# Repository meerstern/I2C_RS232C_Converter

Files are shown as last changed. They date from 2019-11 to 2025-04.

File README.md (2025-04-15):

# I2C_RS232C_Converter
I2C-RS232C Converter with Grove Connector

## 概要 
  * マイコンのI2CポートをRS232C通信ポートに変換するアダプタです
  * マイコンからI2Cデバイスとして制御し、UARTのボーレート設定、送信、受信処理をすることができます
  * I2C/UARTプロトコルブリッジ[SC16IS750][1]とRS232C変換IC ADM3202を搭載しています
  * I2CはGrove互換コネクタとなっており、3.3V/5V電源に対応しています
  * RS232CポートはD-sub9ピンのオスコネクタを搭載しています
  * I2C/UARTプロトコルブリッジSC16IS750は64bytesのバッファを内蔵しています
  * 7.3728MHzの水晶発振子を搭載しており、マイコンのメインクロックから独立してUARTのボーレート設定ができます  
  * デフォルトI2Cアドレスは8bit:0x9A(7bit:0x4D)です  

## 注意 
  * RS232Cレベル変換している信号はD-sub9ピンの受信の2ピン、送信の3ピンのみです  
  * D-sub9ピンの受信の2ピン、送信の3ピン、GNDの5ピン以外はTTLレベルのため、必要に応じて未接続にしてください(v1.0/v1.1のみ)
  * D-sub9ピンの受信の2ピン、送信の3ピン、GNDの5ピン以外のRTS/CDSはRS232Cレベルに変換されています(v1.2以降, v1.3はR14を必要に応じて実装してください)    
  * Arduino Uno以外の場合はサンプルコード内SC16IS750.cppの29行目付近のWire定義を必要に応じて変更してください  

## 販売サイト
  * [スイッチサイエンス][2]

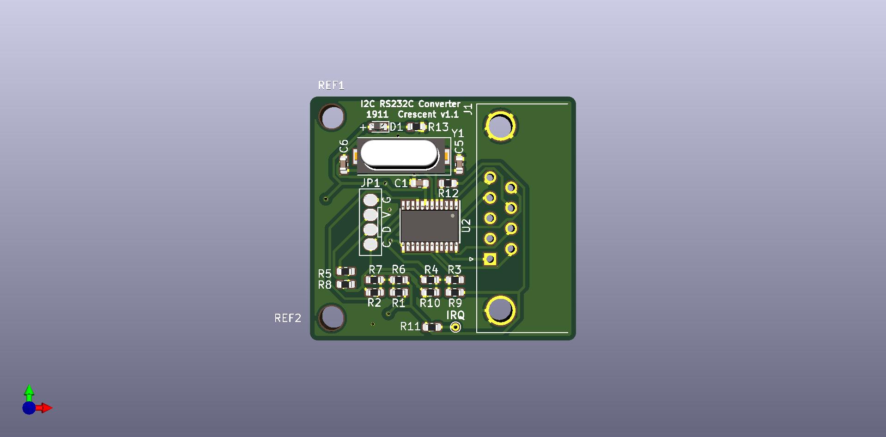
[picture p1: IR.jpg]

   
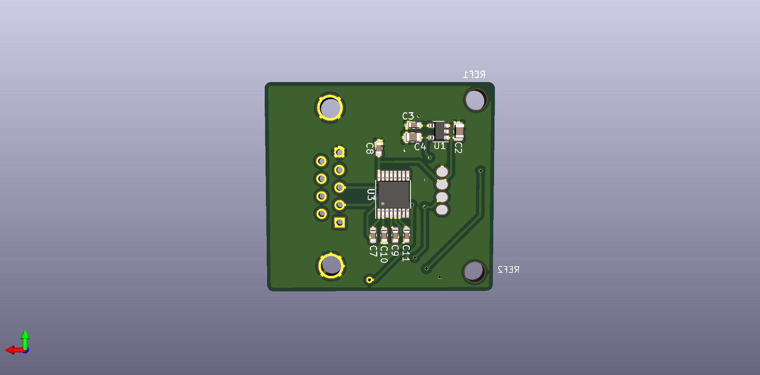
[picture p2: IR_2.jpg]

    
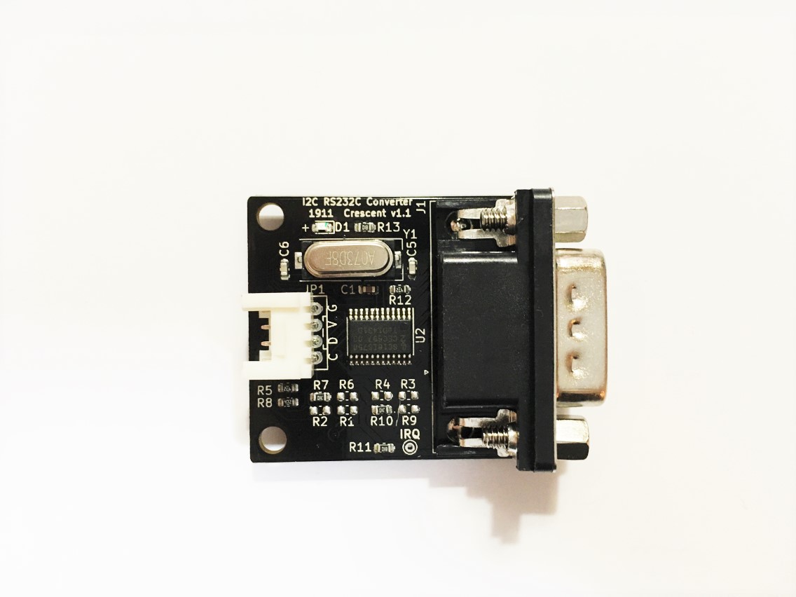
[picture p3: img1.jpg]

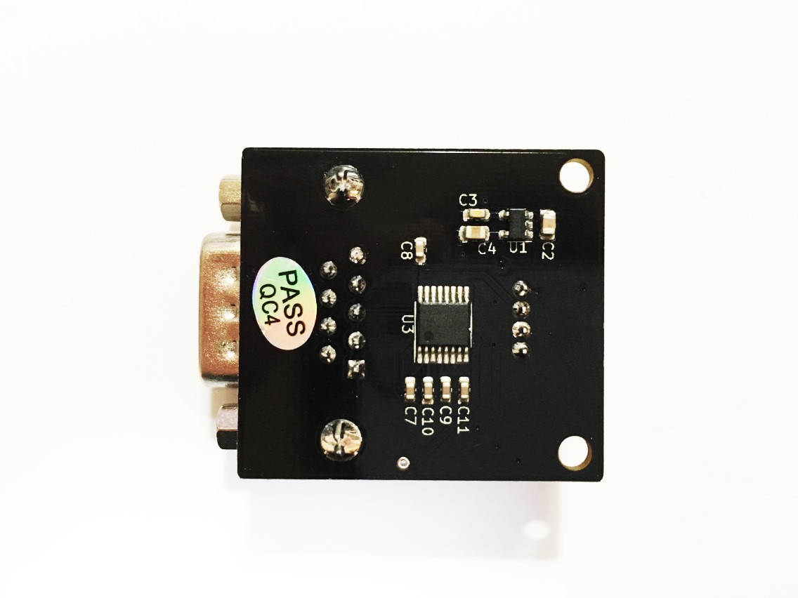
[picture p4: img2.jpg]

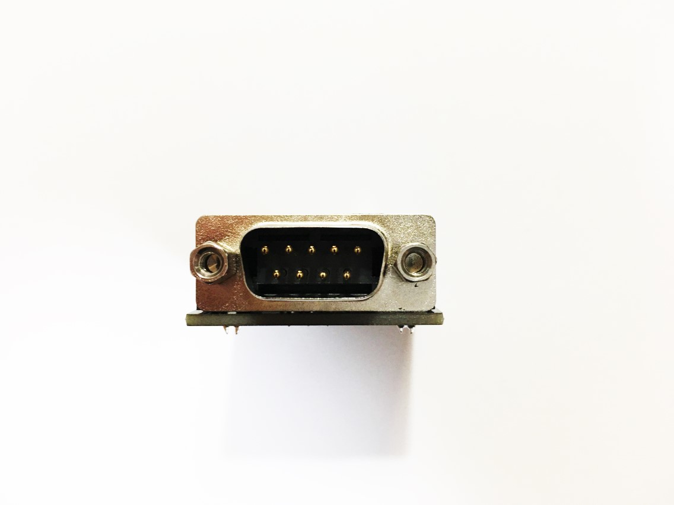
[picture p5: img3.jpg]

    
[1]: https://www.nxp.com/products/peripherals-and-logic/signal-chain/bridges/single-uart-with-i2c-bus-spi-interface-64-bytes-of-transmit-and-receive-fifos-irda-sir-built-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 "*1"

[2]: https://www.switch-science.com/products/6026

MIT Lisense

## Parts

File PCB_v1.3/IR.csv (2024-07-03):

ID | 参照記号 | パッケージ | 数 | 名称 | Supplier and ref
1 | REF2,REF1 | MountingHole_3.2mm_M3 | 2 | MountingHole_3.2mm_M3
2 | JP1 | GROVE | 1 | PINHD-1X4
3 | C1,C7,C8,C9,C10,C11 | C_0603_1608Metric | 6 | 0.1u
4 | C2,C4 | C_0805_2012Metric | 2 | 10u
5 | C3 | C_0603_1608Metric | 1 | 0.01u
6 | C5,C6 | C_0603_1608Metric | 2 | 10p
7 | D1 | D_0603_1608Metric | 1 | LED
8 | R1,R2,R3,R4,R6,R7,R9,R10 | R_0603_1608Metric | 8 | 0
9 | R5,R8,R12 | R_0603_1608Metric | 3 | 4.7k
10 | R11,R13 | R_0603_1608Metric | 2 | 1k
11 | U1 | SOT-23-5 | 1 | LD3985M33R_SOT23
12 | Y1 | Crystal_SMD_HC49-SD | 1 | Crystal
13 | W1 | TestPoint_THTPad_D1.0mm_Drill0.5mm | 1 | IRQ
14 | U2 | TSSOP-24_4.4x7.8mm_P0.65mm | 1 | SC16IS760760IPW
15 | U3 | TSSOP-16_4.4x5mm_P0.65mm | 1 | ADM232A
16 | J1 | DSUB-9_Male_Horizontal_P2.77x2.84mm_EdgePinOffset7.70mm_Housed_MountingHolesOffset9.12mm | 1 | DSUB9

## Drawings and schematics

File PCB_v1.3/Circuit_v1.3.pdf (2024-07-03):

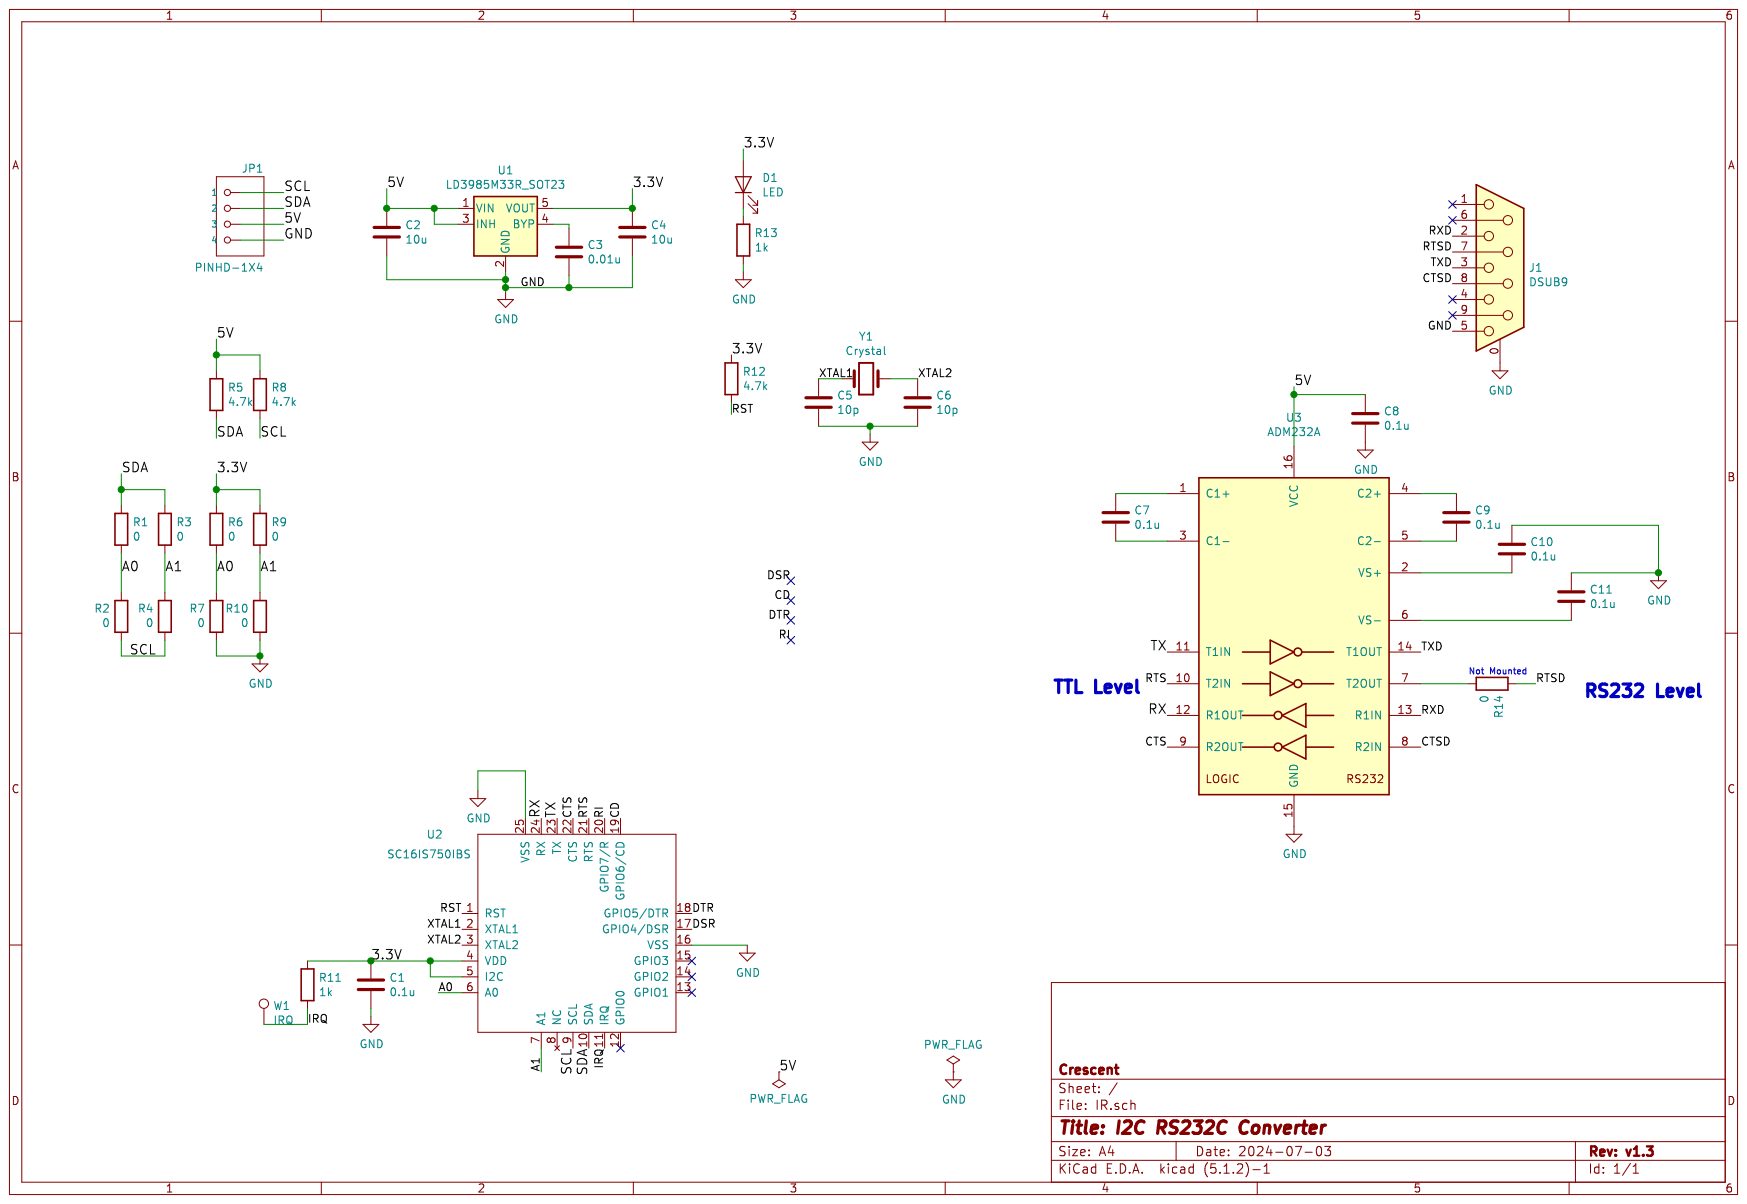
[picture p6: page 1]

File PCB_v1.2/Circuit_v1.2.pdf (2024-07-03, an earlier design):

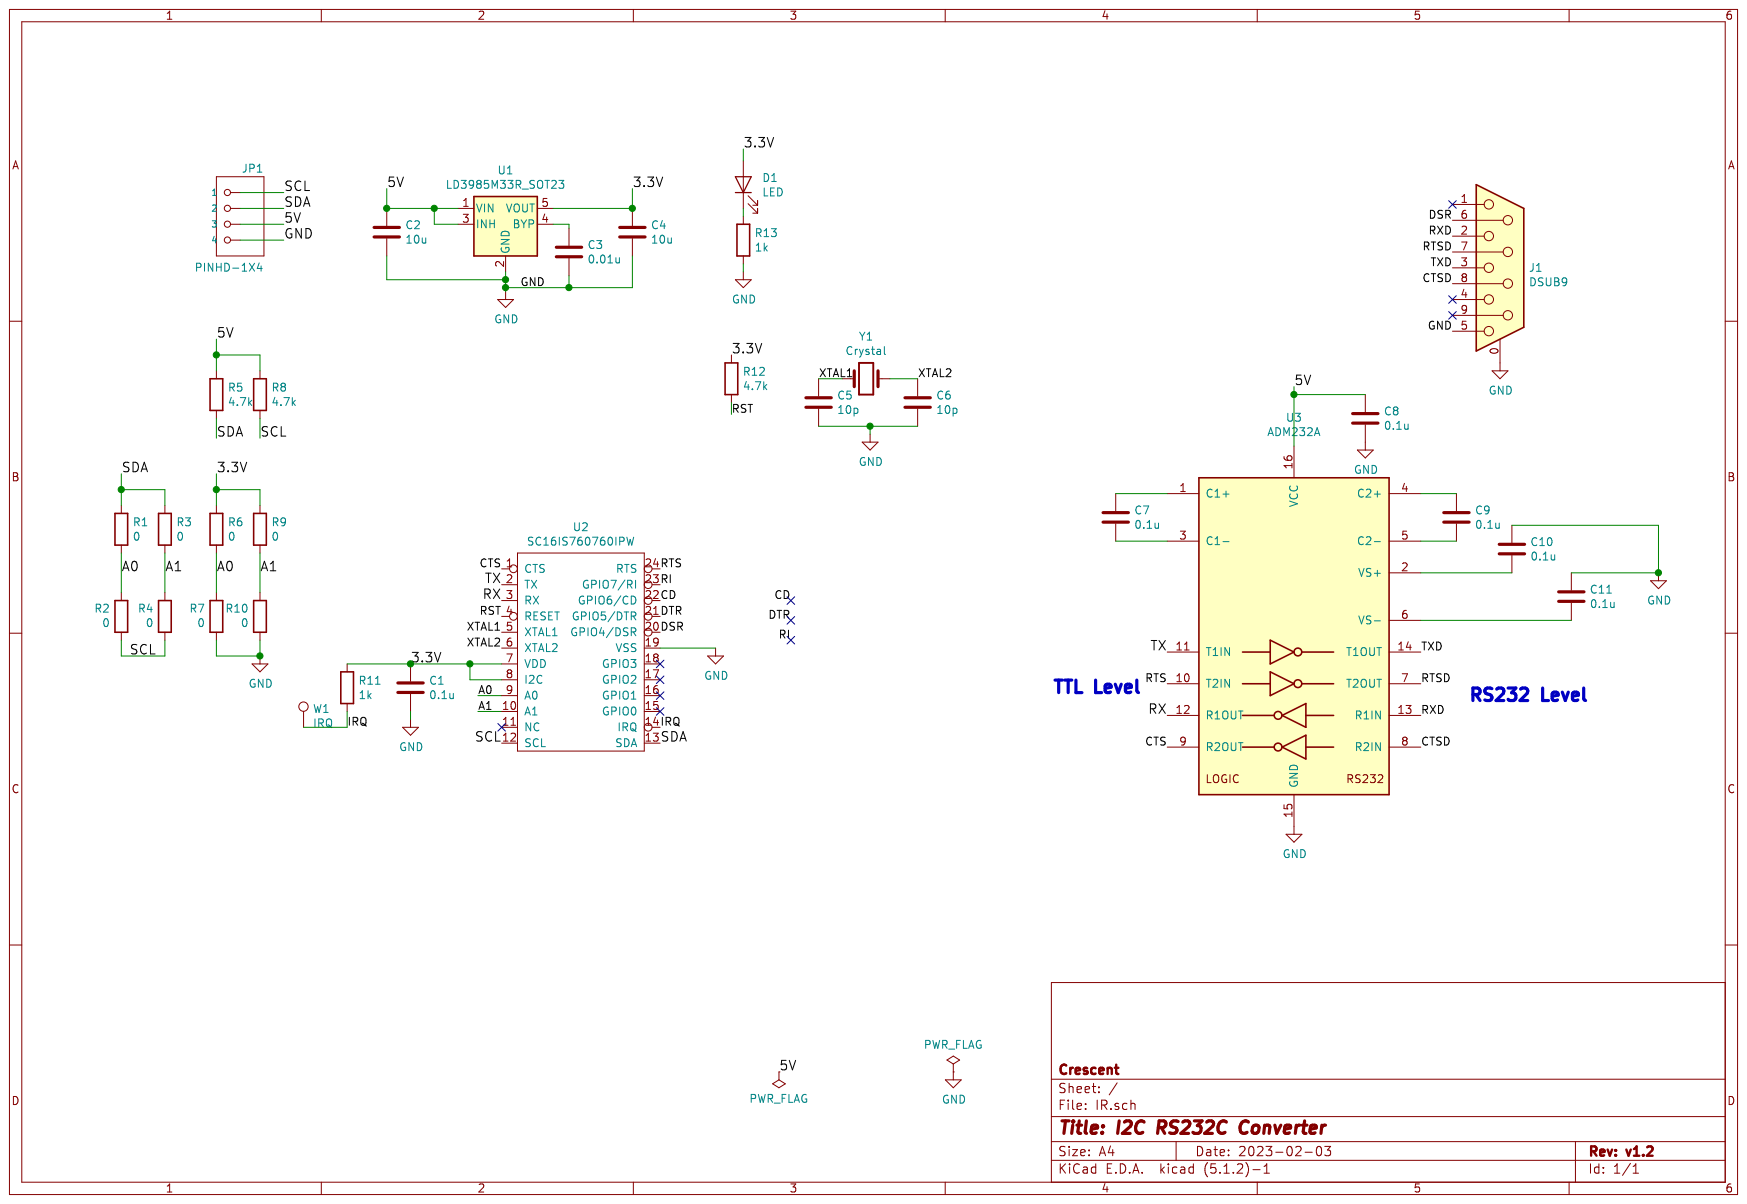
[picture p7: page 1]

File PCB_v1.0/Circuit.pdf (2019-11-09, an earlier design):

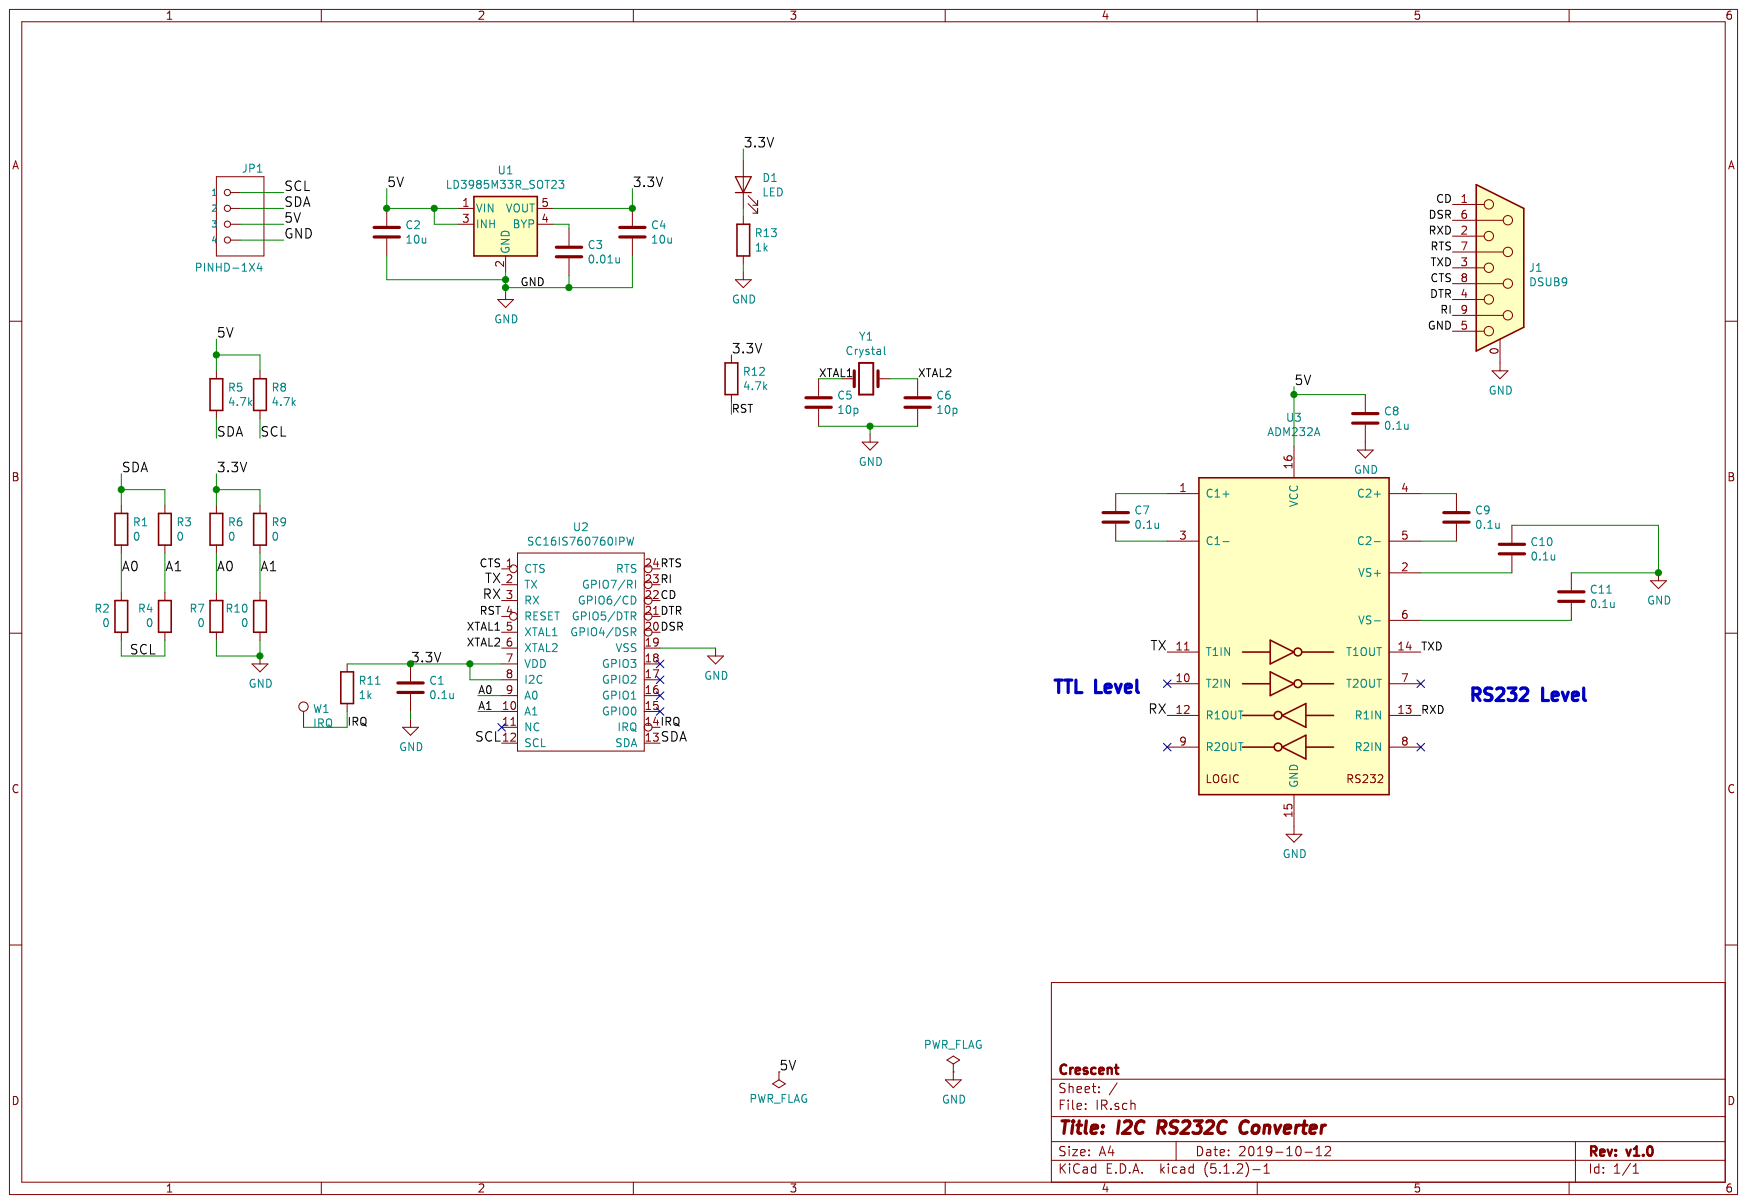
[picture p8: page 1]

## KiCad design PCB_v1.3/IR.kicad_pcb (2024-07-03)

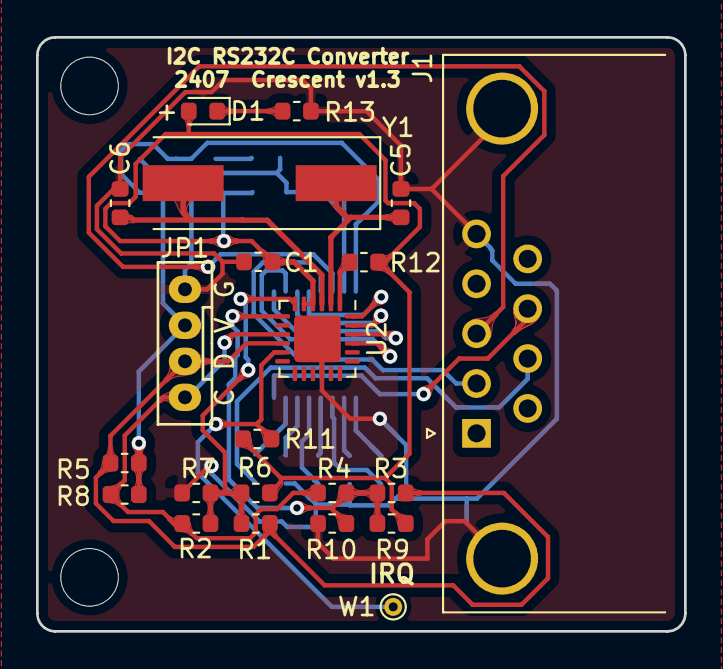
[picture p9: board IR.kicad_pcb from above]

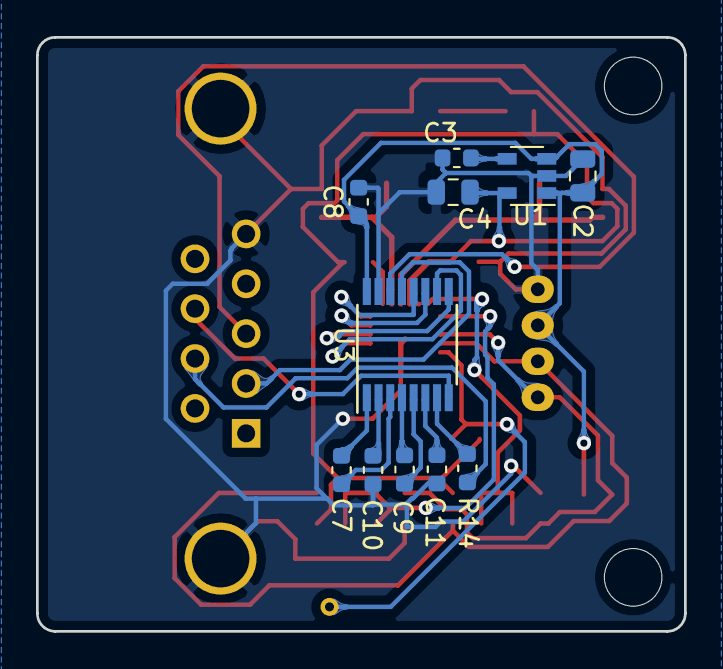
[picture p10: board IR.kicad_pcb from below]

Board: 2 copper layers, 36.0 x 33.0 mm, 35 parts (11 on the bottom side), 28 nets.

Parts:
C1, C7, C8, C9, C10, C11: 0.1u; C_0603_1608Metric
C2, C4: 10u; C_0805_2012Metric
C3: 0.01u; C_0603_1608Metric
C5, C6: 10p; C_0603_1608Metric
D1: LED; D_0603_1608Metric
J1: DSUB9; DSUB-9_Male_Horizontal_P2.77x2.84mm_EdgePinOffset7.70mm_Hou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
JP1: PINHD-1X4; GROVE
R1, R2, R3, R4, R6, R7, R9, R10, R14: 0; R_0603_1608Metric
R5, R8, R12: 4.7k; R_0603_1608Metric
R11, R13: 1k; R_0603_1608Metric
REF1, REF2: MountingHole_3.2mm_M3
U1: LD3985M33R_SOT23; SOT-23-5
U2: SC16IS750IBS; QFN-24-1EP_4x4mm_P0.5mm_EP2.6x2.6mm
U3: ADM232A; TSSOP-16_4.4x5mm_P0.65mm
W1: IRQ; TestPoint_THTPad_D1.0mm_Drill0.5mm
Y1: Crystal; Crystal_SMD_HC49-SD

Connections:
/3.3V: C1.1, C4.1, D1.2, R6.1, R9.1, R11.1, R12.1, U1.5, U2.4, U2.5
/5V: C2.1, C8.1, JP1.3, R5.1, R8.1, U1.1, U1.3, U3.16
/A0: R1.2, R2.2, R6.2, R7.2, U2.6
/A1: R3.2, R4.2, R9.2, R10.2, U2.7
/CTS: U2.22, U3.9
/CTSD: J1.8, U3.8
/IRQ: R11.2, U2.11, W1.1
/RST: R12.2, U2.1
/RTS: U2.21, U3.10
/RTSD: J1.7, R14.1
/RX: U2.24, U3.12
/RXD: J1.2, U3.13
/SCL: JP1.1, R2.1, R4.1, R8.2, U2.9
/SDA: JP1.2, R1.1, R3.1, R5.2, U2.10
/TX: U2.23, U3.11
/TXD: J1.3, U3.14
/XTAL1: C5.1, U2.2, Y1.1
/XTAL2: C6.1, U2.3, Y1.2
GND: C1.2, C2.2, C3.2, C4.2, C5.2, C6.2, C8.2, C10.1, C11.1, J1.0, J1.5, JP1.4, R7.1, R10.1, R13.2, U1.2, U2.16, U2.25, U3.15
unnamed: C3.1, U1.4
unnamed: C7.1, U3.1
unnamed: C7.2, U3.3
unnamed: C9.1, U3.4
unnamed: C9.2, U3.5
unnamed: C10.2, U3.2
unnamed: C11.2, U3.6
unnamed: D1.1, R13.1
unnamed: R14.2, U3.7

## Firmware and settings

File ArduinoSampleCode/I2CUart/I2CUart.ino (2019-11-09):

#include <Wire.h>

#include <string.h>
#include <SPI.h>
#include "SC16IS750.h"


SC16IS750 i2cuart = SC16IS750(SC16IS750_PROTOCOL_I2C,SC16IS750_ADDRESS_BB);

//Connect TX and RX with a wire and run this sketch

void setup() 
{
    Serial.begin(9600);

    // UART to Serial Bridge Initialization
    i2cuart.begin(9600);               //baudrate setting
    Serial.println("Init OK");
    if (i2cuart.ping()!=1) {
        Serial.println("device not found");
        while(1);
    } else {
        Serial.println("device found");
    }
    Serial.println("start serial communication");
    


};

void loop() 
{
   
    i2cuart.write(0x55);
    while(i2cuart.available()==0);
    if (i2cuart.read()!=0x55) {
        Serial.println("serial communication error 1");
        while(1);
    }
    else{
      Serial.println("serial communication OK 1");
    }   
    delay(500);
    
    i2cuart.write(0x0A);
    while(i2cuart.available()==0);
    if (i2cuart.read()!=0x0A) {
        Serial.println("serial communication error 2");
        while(1);
    }
    else{
      Serial.println("serial communication OK 2");
    }   
    
    delay(500);
      
     
  
  

  
};

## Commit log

2019-11-09 Upload data
    [IR-B_Cu.gbl, IR-B_Mask.gbs, IR-B_Paste.gbp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]
2019-11-09 Add Sample Code
2024-07-03 Add V1.3
    [IR-B_Cu.gbl, IR-B_Mask.gbs, IR-B_Paste.gbp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]
